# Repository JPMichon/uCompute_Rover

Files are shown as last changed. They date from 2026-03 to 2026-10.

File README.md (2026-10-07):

# 🤖 uCompute Rover

## [English version available here](./README.EN.md)



## 🛠️ Matériel requis
* 4 x Moteurs réductés CC — "TT Motor" — 200 RPM (3 à 6 VCC)
* 2 x DRV8833 — Contrôleurs de moteur double pont en H (1,5 A, 3 à 10 V)
* 1 x Module uCompute RP2040 ver 1.3 (Rover)
* 1 x uCompute-Rover ver 1.0
* 1 x Convertisseur abaisseur de tension DC-DC LM2596 (3 A ou équivalent)
* 1 x Boîtier pour 6 piles AA (ou équivalent)

## ⚙️ Options et extensions
* 1 x Micro-servomoteur SG90
* 1 x Capteur à ultrasons HC-SR04 / HCSR04
* 1 x Schéma de câblage du rover
* 1 x Interrupteur à bascule encastrable (*Snap-in*) 10x15 mm (ON-OFF)
* 2 x Modules radio nRF24L01+
* 1 x Module uCompute RP2040 ver 1.3 (Télécommande)
* 1 x Contrôleur à distance uCompute (*Remote controller*)
* 1 x Capteur de puissance et moniteur de tension/courant I2C INA219
* 1 x Module GPS GY-NEO-6M avec antenne active en céramique
* 1 x Capteur de distance laser ToF (*Time-of-Flight*) GY-530 VL53L0X
* 1 x Boussole magnétique à trois axes GY-271 QMC5883L (3V-5V)
* 1 x Caméra thermique infrarouge AMG8833 (Matrice de capteurs 8x8)
* 1 x Module haute précision de température, humidité et pression d'air I2C AHT20+BMP280
* 1 x Module d'analyse de la qualité de l'air (CO2, eCO2, TVOC) ENS160+AHT21
* *Tout autre module optionnel selon vos préférences.*

---

## ⚡Vue schématisé de l'électronique embarqué
<p align="center">

</p>

---

# 🔌 Architecture Électronique & Modularité

Le projet **uCompute Rover** repose sur une architecture matérielle entièrement modulaire. Ce dépôt se concentre spécifiquement sur le châssis, l'assemblage mécanique et la carte d'interface du rover (*Rover board*). 

Le « cerveau » et les différents modules de communication requis proviennent de l'écosystème global **RP2040 uCompute**.

---

## 🔗 Dépôt Parent & Documentation Électronique

Pour fabriquer, programmer ou comprendre le fonctionnement détaillé de la carte maîtresse et de ses modules, veuillez vous référer au dépôt principal :

👉 **[GitHub - RP2040 uCompute](https://github.com/JPMichon/RP2040_uCompute)**

Vous y trouverez :
* 📂 Les fichiers de conception matérielle (**Gerber**, schémas de circuits et listes de composants BOM).
* 📂 Les modules.
* 📍 La cartographie complète des ports et les spécifications techniques de la plateforme.

## Guide d'assemblages
Le guide est est séparé en 3 sections ( le matériel, l'électronique et le code ) soit :
* L'assemblage du Rover ce trouve dans le répertoire 📂 [**3D_Parts**](https://github.com/JPMichon/uCompute_Rover/blob/main/README.md)
* L'installation des capteurs et de l'électronique dans le répertoire 📂 [**Electronic**](https://github.com/JPMichon/uCompute_Rover/blob/main/Electronic/README.md)
* Validation du fonctionnement des composantes 📂 **testcode**
  
---

### 🧠 Le Cœur du Système : uCompute
L'intelligence embarquée du robot utilise la plateforme de développement autonome **uCompute** (basée sur le microcontrôleur Raspberry Pi RP2040). C'est elle qui gère l'exécution des scripts de pilotage (MicroPython), l'interface graphique de diagnostic et la centralisation des données des capteurs.<br>


---
### 💡 Une architecture ouverte et universelle

Bien que le projet soit conçu autour de l'écosystème **uCompute** (RP2040), le module de contrôle des moteurs a été développé dans un pur esprit de liberté logicielle et matérielle. L'ensemble de la structure est entièrement agnostique : le module de puissance utilise des signaux logiques **3.3v** . Cela signifie qu'un **maker** peut tout à fait adapter ce châssis et ce module d'extension pour les piloter avec un **ESP32**, un **Arduino** ou toute autre plateforme de développement de son choix, en bricolant son propre module de contrôle ou en utilisant les modules du projet et en adaptant simplement le câblage et le script de pilotage.<br>

 ### 🏎️💨 Pour les Makers plus exigeants
 Il est tout à fait envisageable d'intégrer une solution plus robuste, telle qu'un **Raspberry Pi**. L'utilisation d'un micro-ordinateur de ce calibre permet de gérer des tâches de calcul lourdes ou des scripts plus complexes. Il faudra cependant veiller à ajuster le module d'alimentation du circuit : contrairement aux microcontrôleurs classiques, un Raspberry Pi nécessite une source d'énergie stable et un **courant plus élevé (3A pour un PI 4 Model B) + (1A pour les 4 moteurs) = 4A 5V CC** pour assurer une stabilitée. Une fois cette adaptation électrique logicielle et matérielle effectuée, les possibilités de votre montage s'en trouveront démultipliées.<br>
 
**Libre à vous de créer un Frankenstein! 🧟‍♂️**

---

### 📻 Modules d'extension (Add-ons)
Pour assurer la liaison sans fil et la télémétrie bidirectionnelle avec la télécommande, le rover exploite les modules d'extension interchangeables du projet principal (notamment le module radio **NRF24L01+**).

👉 **[RP2040_uCompute Modules](https://github.com/JPMichon/RP2040_uCompute/tree/main/Modules)**

| Emplacement | Module | Description & Fonctionnalités | Rendu Visuel |
| :--- | :--- | :--- | :--- |
| **Socket Arrière** (Communication) | **Module Wi-Fi** (ESP-12F) | Carte d'adaptation avec ESP8266 pour une connectivité Wi-Fi. |   |
| **Socket Arrière** (Communication) | **Module Radio** (NRF24L01) | Carte d'adaptateur pour liaisons radio 2,4 GHz. |  |
| **Pins Header** <br> (Connecteur IOs) | **µCompute Remote** <br> (REV 1.0) | Module de commande analogue avec boutons. |  |
| **Pins Header** <br> (Connecteur IOs) | **µCompute Rover** <br> (REV 1.0) | Contrôleur de moteur DC (2+2) + Servo + HC-SR04 + Module GPS (Neo-6M). |  |

---

## 🎮 Contrôle à distance (Mode RC)

Le **uCompute Rover** intègre un mode de pilotage radiocommandé (RC) autonome. La télécommande est construite autour d'un second module uCompute équipé d'un joystick analogique, de boutons-poussoirs, d'un écran OLED **SSD1306** et d'un module radio **NRF24L01+**.

<p align="center">
  
</p>

### 📐 Conception mécanique et boîtier 3D
L'ergonomie de la manette a été spécialement étudiée pour offrir une prise en main confortable grâce à des poignées latérales intégrées. 

* 📁 Le fichier STL du boîtier est disponible ici : **[RC_remote_v1.stl](https://github.com/JPMichon/uCompute_Rover/blob/main/3D_Parts/RC_remote_v1.stl)**

### 💾 Scripts de test (MicroPython)
Le système s'appuie sur deux scripts distincts qui gèrent la communication bidirectionnelle en temps réel (envoi des commandes de pilotage et réception de la télémétrie sur l'écran OLED) :

1. **Côté Télécommande :** **[Remote_Rover_v1_SSD1306.py](https://github.com/JPMichon/uCompute_Rover/blob/main/testcode/Remote_Rover_v1_SSD1306.py)**
   * Initialise le bus SPI pour le module radio NRF24L01+.
   * Lit l'état du joystick analogique (axes X/Y) et des boutons de commande.
   * Gère l'affichage des informations système sur l'écran OLED local.
   * Transmet les paquets de commande vers le robot de manière périodique.

2. **Côté Rover :** **[RC_Rover_v1_SSD1306.py](https://github.com/JPMichon/uCompute_Rover/blob/main/testcode/RC_Rover_v1_SSD1306.py)**
   * Reste à l'écoute des paquets radio émis par la télécommande.
   * Décode les consignes de trajectoire et de vitesse pour piloter les moteurs CC via les ponts en H DRV8833.
   * Gère la sécurité (arrêt d'urgence automatique des moteurs en cas de perte de liaison radio).

---

## 🚀 Évolution vers un Rover Autonome et Télémétrie

Bien que le projet soit initialement présenté avec un mode de pilotage radiocommandé (RC), l'architecture matérielle du **uCompute Rover** a été pensée dès le départ pour la modularité. Grâce à ses nombreux capteurs embarqués, le robot peut très facilement être transformé en **véhicule 100 % autonome**.

### 🤖 Logique d'Autonomie Évolutive
La carte d'interface (*Roverboard*) interconnecte nativement tous les éléments essentiels pour permettre au microcontrôleur RP2040 de prendre des décisions en temps réel :
* **Évitement d'obstacles :** Le capteur à ultrasons **HC-SR04** (ou le capteur laser ToF **VL53L0X**) permet de cartographier l'environnement direct et d'adapter la trajectoire.
* **Navigation et orientation :** L'ajout de la boussole magnétique **GY-271** et du module GPS **NEO-6M** ouvre la voie à des algorithmes de navigation par points de passage (*waypoints*).

Le passage au mode autonome ne nécessite aucune modification matérielle majeure : il s'agit principalement d'un **déploiement logiciel** (scripts de contrôle de trajectoire automatique en MicroPython).

### 🌐 Pilotage par Interface Web (Wi-Fi)
Puisqu'un module **Wi-Fi (ESP-12F)** est disponible dans l'écosystème uCompute (conçu pour s'insérer sur le socket arrière de communication), les possibilités de contrôle à distance s'étendent au réseau IP. 

En déployant un micro-serveur HTTP en MicroPython sur l'uCompute, il devient possible de :
* **Piloter le rover depuis n'importe quel appareil** (smartphone, tablette ou PC) connecté au même réseau Wi-Fi, sans avoir besoin d'une manette physique.
* Créer une **interface web moderne et interactive** (boutons tactiles, sliders de vitesse, joystick virtuel en JavaScript) pour contrôler les mouvements du robot en toute simplicité.

  ### 📡 Liaison Longue Portée (LoRa)
Grâce au bus SPI exposé sur le socket arrière, l'intégration d'un module radio **LoRa** (comme le RFM95W ou équivalent) est également envisageable avec très peu d'efforts. Cette technologie permet d'étendre radicalement le rayon d'action du rover, autorisant la transmission de commandes et de télémétrie sur de très longues distances en extérieur (milieu rural ou urbain dense), là où le Wi-Fi ou les liaisons 2,4 GHz classiques s'essoufflent. 

*Note : Un add-on LoRa standardisé fait partie des pistes de réflexion et pourrait être officiellement disponible dans les prochaines évolutions de la plateforme uCompute.*

### 📊 Télémétrie Bidirectionnelle en Temps Réel
En mode autonome, les modules radio **NRF24L01+** changent de rôle. Au lieu de simplement recevoir des commandes de pilotage, le lien sans fil sert à renvoyer un flux constant de données (télémétrie) vers une station au sol (PC, console ou le module *uCompute Remote*) :
* Surveillance en temps réel de la tension et du courant consommé (via le capteur de puissance **INA219**).
* Transmission des coordonnées géographiques (GPS), du cap (boussole) et des conditions environnementales (température, pression via le **BME280**).
* Visualisation des données thermiques à distance si le capteur infrarouge **AMG8833** est installé.

*Un ensemble de scripts exemples dédiés à la navigation autonome et au protocole de communication de télémétrie sera progressivement ajouté au dossier `testcode`.*

---

# 🎯 Le projet idéal pour vous lancer

Vous rêvez de construire votre propre plateforme de robotique avancée, mais vous ne savez pas par où commencer ? Vous avez peur de manquer de temps, de connaissances en programmation ou d'expertise en électronique ? Vous craignez de vous perdre dans un fouillis de câbles qui se débranchent tout le temps, ou de bloquer vos élèves avec du code trop complexe ?

Le **uCompute Rover** a été créé précisément pour en finir avec ces frustrations.

## 🧠 Pas besoin d'être un expert pour débuter
* **Zéro programmation complexe :** Oubliez le C++ austère. Le robot est propulsé par le microcontrôleur RP2040 et se programme en **MicroPython**. C'est le langage le plus simple, le plus lisible et le plus rapide à apprendre aujourd'hui. En quelques lignes de code, votre robot avance.
* **Zéro blocage frustrant :** Grâce au système visuel intégré (*uComputeOS*), si vous ou l'un de vos élèves faites une erreur dans le code, l'écran affiche une alerte claire au lieu de faire planter complètement la carte. Vous comprenez l'erreur instantanément sans perdre de temps.

## 🛠️ Zéro soudure si vous le souhaitez !
* Vous pensez ne pas avoir le niveau pour souder de minuscules composants électroniques (CMS) ? Aucun problème. Bien que la carte finale soit ultra-propre, le projet est conçu pour être **100 % reproductible sur une simple plaque de prototypage (*Breadboard*)** avec un Raspberry Pi Pico ou Pico 2 classique à bas coût. C'est la solution idéale pour débuter rapidement à la maison ou équiper toute une classe avec un budget maîtrisé.

## 🚀 Une évolution sans limites, à votre rythme
Ne restez pas bloqué avec un robot jouet figé. Commencez par un châssis basique télécommandé en ligne droite, puis faites-le évoluer quand vous aurez le temps : ajoutez le Wi-Fi pour le piloter depuis votre smartphone, connectez un module radio longue portée, ou installez un GPS et un capteur de distance pour le rendre totalement autonome.

## 🛠️ Pour les Makers : Le bac à sable ultime
* **Modularité totale :** Finis les robots figés ou les amas de câbles *Dupont* instables. Grâce à son système de cartes filles interchangeables, faites évoluer votre rover au gré de vos envies : ajoutez le Wi-Fi (ESP-12F), la radio (NRF24L01+), le LoRa, un GPS ou de l'imagerie thermique sans jamais refaire le circuit principal.
* **Architecture ouverte :** Explorez des protocoles industriels et de communication standardisés (I2C, SPI, UART, PWM) sur une plateforme robuste et gratifiante.

## 🎓 Pour les Écoles & Projets Éducatifs : Une pédagogie sans friction
* **Barrière à l'entrée minimale :** Propulsé par le microcontrôleur RP2040 et les technologies d'uCompute, le rover permet aux étudiants de comprendre et d'obtenir des résultats concrets en seulement quelques lignes de code, bien plus rapidement qu'en C++.
* **Sécurité et tolérance aux erreurs :** Grâce à l'interface de diagnostic intégrée (*uComputeOS*), si le code d'un élève contient une erreur, la carte capture l'exception et affiche un écran d'alerte visuel au lieu de figer le robot. L'apprentissage se fait par expérimentation fluide, sans frustration.
* **Accessible à tous les budgets :** Si l'assemblage CMS d'origine demande de l'expertise, la plateforme est **100 % rétrocompatible sur plaque de prototypage (*Breadboard*)** avec un Raspberry Pi Pico ou Pico 2 standard. Vous pouvez équiper une classe entière à moindre coût !

*Le uCompute Rover vous fournit une base mécanique et électronique solide. Vous n'avez plus qu'à assembler les blocs, à votre rythme et selon vos compétences actuelles.*

---

## 📜 Licence

Le matériel (fichiers de conception, schémas, typons) et les logiciels de ce projet sont mis à disposition selon les termes de la Licence **Creative Commons Attribution - Pas d'Utilisation Commerciale - Partage dans les Mêmes Conditions 4.0 International (CC BY-NC-SA 4.0)**.

❌ **L'utilisation commerciale de ce projet (revente de PCBs nus, kits ou cartes retroPico assemblées) est strictement interdite sans autorisation préalable de l'auteur.**

Consultez le fichier [LICENSE](LICENSE) pour lire l'intégralité des termes.

---

## ☕ Soutenir le projet

Si vous appréciez mon travail et souhaitez m'offrir un café pour me soutenir bénévolement dans mes futurs projets de soudure et de code, vous pouvez me laisser un [**pourboire sur Ko-fi** ](https://ko-fi.com/jpmichon) . C'est entièrement volontaire et grandement apprécié !

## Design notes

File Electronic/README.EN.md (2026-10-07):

# ⚡ uCompute Rover Wiring

This directory contains all the necessary information to assemble, wire, and power the robot's electronic components.

## 🗺️ Schematic View of the Onboard Electronics
<p align="center">

</p>

---

# Assembly Guide

<br>

## ⚙️ Motor Installation

### **You will need:** <br>
• 8 screws (25 mm x 3 mm), <br>
• 4 self-tapping screws (3 mm x 5 mm), <br>
• 4 all-terrain wheels, <br> 
• 4 TT dual-shaft DC motors 3-6 V, 200 RPM ratio, 1:48 reduction, <br>      
 <br>

**Extend the motor wires as needed**: My prototype version uses **JST-XH 2.54 2-pin** connectors.<br> 
Feel free to use your own setup.

Each motor is connected using a 26 AWG two-conductor wire measuring approximately **30 cm**.

### Steps:

| Insert the wire into the top hole | Insert each wire on each side | Solder the wires to the motor terminals | Secure the motor using screws | Route the other end out the bottom of the electronics plate | Add a sticker on the axles of the 4 motors |
| :---: | :---: | :---: | :---: | :---: | :---: |
|  |  |  |  |  |  

>[!NOTE]
> To **save yourself some time**, make sure to always solder the positive and negative terminals in the same order, as the power module reverses the polarity of the second motor on the same **side**. **This means that if the motors run backward** instead of forward, **you must** swap the connectors between the two motors. <br>
> <br>
> Another element: the **right and left motors operate in pairs**. **That is to say**, the **two** motors on the same side are wired to be synchronous. This reduces **the number of I/Os (IOs)** required to control the motors. The other advantage is that it makes it easier to use **tracks** without having to implement software safeguards, while allowing for more features on the Rover Board. However, **every advantage has its drawbacks**, and this configuration **does not allow** for the use of **Mecanum wheels**. Since the **uCompute Rover is modular** and the schematics are available, **it is relatively simple to DIY your own** motor control module. It is not impossible that in the near future, I might add a specific module to control **Mecanum wheels**.

## ⚙️ Installing the Control Modules

### **You will need:** <br>
• 1 x RP2040 uCompute module,<br>
• 1 x uCompute Rover module,<br>
• 2 x DRV8833 modules,<br>
• 8 self-tapping screws (3 mm x 5 mm),<br>

### Installation:

| Prepare 4 mounting screws | Secure the <br> RP2040 uCompute module | Prepare 4 mounting screws | Secure the <br> uCompute Rover module | Connect the right <br> and left motors | Insert the DRV8833 modules <BR> (Output pins facing down) |
| :---: | :---: | :---: | :---: | :---: | :---: |
| |  |  |  |  | 

## ⚙️ Installing the Power Switch
### **You will need:** <br>
• 1 x 24 AWG two-conductor wire, approximately 20 cm,<br>
• 1 x SPST rocker switch, model: **KCD11 (10X15mm)**,<br>

### Installation:

| Solder the wires to the switch terminals | Insert the switch into the square hole on the control panel |
| :---: | :---: |
||

## :scissors: Mounting the Power Supply
This section is simple, yet effective…<BR>
The easiest way to hold the various components in place is by using Velcro strips.<br>
_If it's good enough for NASA, it's good enough for the Rover!_

### Steps:

| Stick a Velcro strip <br> on the top shelf | Stick Velcro strips <br> under the battery holder | Stick a Velcro strip <br> under the regulator | Test the installation |
| :---: | :---: | :---: | :---: |
| | |||

## ⚙️ Preparing and Installing the NeoPixel Strip

> [!NOTE]
> Only available for the `frontal_sensor_v3.stl` which natively integrates the **NeoPixel** strip.

### **You will need:** <br>
• 3 x wires with a female **DuPont** connector on one end, approximately **25 cm** long,<br>
• 1 x **NeoPixel** strip with 8 addressable **WS2812B** (5050) LEDs,<br>
• 2 self-tapping screws (3 mm x 5 mm),<br>

### Steps:

| View of the NeoPixel strip | Solder the wires <br> to the side labeled DI | Result | Prepare 2 mounting screws | Secure the NeoPixel module <br> underneath the sonar |
| :---: | :---: | :---: | :---: | :---: |
| |  |  |  | |

## :scissors: Installing the HC-SR04 Sonar
For this part, you will need **hot glue…** <br>
Hooray for crafting! <br>

### **You will need:** <br>
• 4 x wires with female-to-female **DuPont** connectors, approximately **25 cm** long,<br>
• 1 x HC-SR04 Sonar Module<br>

### Steps:

| Installing the **DuPont connectors** <br> on the sonar | Installing the sensor in its housing <br> use a little hot glue to secure it |
| :---: | :---: |
|||

> [!NOTE]
> Hot glue has a melting point around 190°C (374°F), which is very close to 3D printing temperatures. <br>
> **Use hot glue sparingly** to avoid warping your printed parts.

## ⚙️ Installing the Servo Motor
### **You will need:** <br>
• 1 x **SG90 Mini Gear Micro 9g** Servo or equivalent,<br>
• 2 self-tapping screws (2 mm x 5 mm) (usually included with the Servo).<br>

### Steps:

| Servo Image | Prepare 2 Screws | Secure the Servo <br> to the Mount |
| :---: | :---: | :---: |
| |  | |

## ⚙️ Preparing the LM2596
### **You will need:** <br>
• 1 x 24 AWG two-conductor wire, approximately 10 cm,<br>
• 1 x 24 AWG two-conductor wire, approximately 15 cm, with a **JST XH2.54 2P** connector on one end,<br>
• 1 x **LM2596 DC-DC buck converter** module,<br>

### Steps:

| Solder the wires<br> + Red, - Black | Close-up of the <br> JST XH2.54 2P connector | 
| :---: | :---: |
|||

> [!WARNING]
> ### ⚡ WARNING: Mandatory Tuning of the LM2596 Regulator
> The Rover module strictly requires a **5V** power supply voltage. Since the LM2596 DC-DC converter is an **adjustable** regulator, it is **crucial to adjust its output voltage to 5V using a multimeter BEFORE connecting it** to the Rover's electronic boards.
> 
> Connecting the regulator without prior adjustment or with a voltage that is too high will lead to the **immediate destruction** of the RP2040 microcontroller, the LCD screen, and all of your sensors.

### Adjusting the Regulator

**Using a multimeter and a small flathead screwdriver, adjust the voltage by turning the potentiometer screw (indicated in the photo below).**
> 🔄 **Potentiometer Adjustment Direction:**
> * **To DECREASE the voltage:** Turn the screw **counterclockwise**.
> * **To INCREASE the voltage:** Turn the screw **clockwise**.
> 
> *Note: These multi-turn potentiometers often have a wide initial adjustment range. It is completely normal to have to complete several full turns (sometimes more than 10 to 15 turns) before seeing the voltage begin to change on your multimeter. Proceed gently with small adjustments once you are close to 5V.*

<p align="center">

</p>

## 🔋 Power Supply Diagram

The Rover is powered by a 6-AA battery pack (or equivalent). The voltage is stepped down to **5V (2A min)** via the LM2596 module to power the main board, the motors, and the servo motor.

<p align="center">

</p>

---

## Final Connections
The power supply, the HC-SR04 Sonar, and the Servo all connect to this specific location on the control board.<br>
The **NeoPixels** connect directly to the uCompute board.<br>

The motors were already connected in the previous steps. If they aren't, you can connect them now.<br> 

### Steps:

| Close-up of the connectors | Once connected | Connect the NeoPixel <br> directly to the uCompute | Connect the INA219 <br> to the back of the uCompute |
| :---: | :---: | :---: | :---: |
| |  | ||

## Cable Management (Optional):

### **You will need:** <br>
• A **sufficient quantity** of **10 cm cable ties (zip ties / tie-wraps)**.<br>
• A pair of **wire cutters** to trim off the excess.

Although optional, this part is nevertheless important if you **want** a reliable project over time. The horizontal pieces were designed with notches to make cable management easier, allowing the use of **10 cm cable ties (zip ties)** to secure the **cables** firmly. Feel free to use them as you see fit.

### Location of the notches<br>


## GPS Connection
**Coming soon**

## Telecommunication Module Connection
**Coming soon**

---

# EXTRA

## More than one I2C sensor? No problem!
There is a good chance you will want to include more than one I2C sensor in your project. The solution is quite simple and can be achieved by connecting them in parallel using a quick DIY trick.

### DIY Details

| Top View | Soldering Details | 
| :---: | :---: |
| |  |

> [!NOTE]
> 💡 **Important note regarding the I2C bus**
> * The I2C bus requires two pull-up resistors—one on SDA and one on SCL—connected to VCC to function properly.
> * Most ready-to-use sensor modules (breakout boards) already include these built-in resistors.
> * Connecting too many modules in parallel drops the total pull-up resistance (Ohm's law / resistors in parallel). If you connect more than 3 or 4 sensors, the signal quality may degrade.
> 
> ⚠️ **In case of issues:** If you experience communication errors, you will need to remove (unsolder) the pull-up resistors from some of the modules to keep only a single pair on the entire bus.

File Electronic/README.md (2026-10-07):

# ⚡ Câblage du uCompute Rover

Ce répertoire regroupe toutes les informations nécessaires pour assembler, câbler et alimenter les composants électroniques du robot.

## 🗺️ Vue schématisée de l'électronique embarquée
<p align="center">


</p>

---

#  Guide de montage

<br>

## ⚙️ Installation des moteurs

### **Vous aurez besoin de:** <br>
• 8 vis de (25 mm x 3 mm), <br>
• 4 vis perçante de (3 mm  x 5 mm), <br>
• 4 roues tout-terrain, <br> 
• 4 moteurs TT double CC 3-6 V Rapport 200 tr/min, réduction 1:48, <br>      
 <br>

**Alonger les fils des moteurs aux besoins** :  Ma version prototype utilise des connecteurs **JST-XH 2.54 2-pin**<br> 
Libre à vous d'utiliser votre propre recette.

Chaque moteur est raccordé par un fil à deux conducteurs de calibre 26 AWG d'environ **30 cm**.

### Étapes:
| Insérer le fil dans le trou du haut | Insérer chaque fil de chaque côté | Souder les fils aux bornes du moteur | Sécuriser le moteur à l'aide de vis | Sortir l'autre extrémité dans le bas de la plaque électronique | Ajouter un collant sur les axes des 4 moteurs 
| :---: | :---: | :---: | :---: | :---: | :---: |
|  |  |  |  |  |  

>[!NOTE]
> Afin de **vous faire gagner du temps**, assurez-vous de toujours souder la borne positive et la borne négative dans le même ordre, car le module de puissance inverse la polarité du second moteur d’un même **côté**. **Cela signifie que si les moteurs reculent** au lieu d’avancer, **il faut** inverser les connecteurs entre les deux moteurs. <br>
> <br>
> Autre élément : les **moteurs droit et gauche fonctionnent** par **paire**. **C'est-à-dire** que les **deux** moteurs d’un même côté sont câblés pour être synchrones. Cela permet de diminuer **le nombre d'E/S (IOs)** requis pour piloter les moteurs. L’autre avantage est de faciliter l’utilisation de **chenilles** sans devoir mettre en place des garde-fous logiciels, tout en permettant plus de fonctionnalités sur le Rover Board. Cependant, **tout avantage ayant ses inconvénients**, cette configuration **ne permet pas** l’utilisation de **roues Mecanum**. Comme le **uCompute Rover est modulaire** et les schémas sont disponibles, **il est relativement simple de bricoler votre propre module** de contrôle des moteurs. Il est impossible, que dans un avenir plus ou moins rapproché, j'ajoute un module spécifique pour piloter des **roues Mecanum**.

## ⚙️ Installation des modules de controle

### **Vous aurez besoin de:** <br>
• 1 x module RP2040 uCompute,<br>
• 1 x uCompute Rover module,<br>
• 2 x Module DRV8833
• 8 vis perçante de (3 mm  x 5 mm), <br>

### Installation:
| Préparer 4 vis de montage | Fixer le module <br> RP2040 uCompute | Préparer 4 vis de montage | Fixer le module <br> uCompute Rover | Raccorder les moteurs <br> droite et gauche | Insérer les modules DRV8833 <BR> (broches Output vers le bas)|
| :---: | :---: | :---: | :---: | :---: | :---: |
| |  |  |  |  | 

## ⚙️ Installation de l'interrupteur d'alimentation
### **Vous aurez besoin de:** <br>
• 1 x fil à deux conducteurs de calibre **24 AWG** d'environ **20 cm**.,<br>
• 1 x un interrupteur à bascule SPST modele: **KCD11 (10X15mm)**,<br>

### Installation:
| Souder le fils sur les bornes de l'interrupteur | Insérer l'interrupteur dans le trou carré du panneau de controle |
| :---: | :---: |
||

## :scissors: Fixation de l'alimentation
Cette section est simple, mais efficace…<BR>
Pour maintenir en place les différents composants, la façon la plus simple reste l’utilisation de bandes Velcro.<br>
_Si c’est assez bon pour la NASA, c’est bon pour le Rover !_

### Étapes:
| Coller une bande de Velco <br> sur la tablette du haut | Coller des bandes de Velco <br> sous le porte-piles | Coller une bande de Velco <br> sous le régulateur | Tester l'installation |
| :---: | :---: | :---: | :---: |
| | |||

## ⚙️ Préparation et installation de la bande NeoPixel

> [!NOTE]
> Seulement disponible pour le  `frontal_sensor_v3.stl` intégrant nativement la bande **Neopixel**.
> 
### **Vous aurez besoin de:** <br>
• 3 x fils avec connecteur **DuPont** femelle a l'un des bouts. Longueur environ **25 cm**,<br>
• 1 x bande **Neopixel** de 8 x **WS2812B** (5050) adressables,<br>
• 2 vis perçante de (3 mm  x 5 mm), <br>

### Étapes:
| Vue de la bande Neopixel | Souder les fils <br> sur le coté  avec DI  | Résultat | Préparer 2 vis de montage | Fixer le module NeoPixel <br> sous le sonar |
| :---: | :---: | :---: | :---: | :---: |
| |  |  |  | |

## :scissors: Installation du Sonar HC-SR04
Pour cette partie, vous aurez besoins de **colle chaude…** <br>
Vivement l'artisanat! <br>

### **Vous aurez besoin de:** <br>
• 4 x fils avec connecteur **DuPont** femelle au deux bouts. Longueur environ **25 cm**,<br>
• 1 x Module de Sonar HC-SR04<br>

### Étapes:
| Installation des **fiches Dupont** <br> sur le sonar | Installation du capteur dans son socle <br> un peu de colle chaude pour le tenir en place |
| :---: | :---: |
|||

> [!NOTE]
> La colle chaude a un point de fusion au alentour de 190 °C. très près des températures d'impression des pièces en 3D. <br>
> **Allez y parcimonieusement** avec la colle chaude pour évitez de déformer vos pièces.

## ⚙️ Installation du servo moteur
### **Vous aurez besoin de:** <br>
• 1 x **SG90 Mini Gear Micro 9g** Servo ou équivallent,<br>
• 2 vis perçante de (2 mm  x 5 mm). (généralement inclus avec le Servo). <br>
### Étapes:
| Image du servo | Préparer 2 vis | Fixer le servo <br> au support |
| :---: | :---: | :---: |
| |  | |

## ⚙️ Préparation du LM2596
### **Vous aurez besoin de:** <br>
• 1 x fil à deux conducteurs de calibre **24 AWG** d'environ **10 cm**.,<br>
• 1 x fil à deux conducteurs de calibre **24 AWG** d'environ **15 cm**  avec un connecteur **JST XH2.54 2P** à l'un des bout,<br>
• 1 x un module **convertisseur DC-DC LM2596**,<br>
### Étapes:
| Souder les fils<br>  + rouge, - Noir | Gros plan sur le  <br>connecteur JST XH2.54 2P | 
| :---: | :---: |
|||

> [!WARNING]
> ### ⚡ ATTENTION : Réglage impératif du régulateur LM2596
> Le module du Rover requiert une tension d'alimentation stricte de **5 V**. Le convertisseur DC-DC LM2596 étant un régulateur **ajustable**, il est **crucial d'ajuster sa tension de sortie à 5 V à l'aide d'un multimètre AVANT de le connecter** aux cartes électroniques du Rover. 
> 
> Brancher le régulateur sans réglage préalable ou avec une tension trop élevée entraînera la **destruction immédiate** du microcontrôleur RP2040, de l'écran LCD et de l'ensemble de vos capteurs.

### Ajustement du régulateur

**À l’aide d’un multimètre et d’un petit tournevis plat, ajustez la tension en tournant la vis du potentiomètre (indiquée sur la photo ci-dessous).**
> 🔄 **Sens de réglage du potentiomètre :**
> * **Pour DIMINUER la tension :** Tournez la vis dans le **sens inverse des aiguilles d'une montre** (antihoraire).
> * **Pour AUGMENTER la tension :** Tournez la vis dans le **sens des aiguilles d'une montre** (horaire).
> 
> *Note : Ces potentiomètres multitours possèdent souvent une large plage de réglage initiale. Il est tout à fait normal de devoir effectuer plusieurs tours complets (parfois plus de 10 à 15 tours) avant de voir la tension commencer à varier sur votre multimètre. Procédez par petits gestes une fois proche des 5 V.*

<p align="center">

</p>

## 🔋 Schéma de l'alimentation électrique

Le Rover est propulsé par un boîtier de 6 piles AA (ou équivalent). La tension est abaissée à **5 V (2 A min)** via le module LM2596 pour alimenter la carte principale, les moteurs et le servomoteur.

<p align="center">

</p>

---

## Le branchement finale
L'alimentation, le Sonar HC-SR04 et le Servo ce connecte tous a cet endroit sur la carte de controle.<br>
Les **Neopixels** ce connecte directement sur le uCompute.<br>

Les moteurs ont déjà été connecté précédemment. Si il ne le sont pas, vous pouvez les connecter. <br> 

### Étapes:
| Gros plan sur les connecteurs | une fois connectés| Branchez le Neopixel <br> directement sur le uCompute | Branchez le INA219 <br> à l'arrière du uCompute |
| :---: | :---: | :---: | :---: |
| |  | ||

## Gestion du câblage (facultatif):

### **Vous aurez besoin de:** <br>
• **Serre-câbles (Tie-Wraps)** de **10 cm** en nombre **suffisant**.<br>
• Une paire de **pinces coupantes** pour retirer la partie superflue.

Bien que facultative, cette partie est néanmoins importante si vous **désirez** avoir un projet fiable dans le temps. Les pièces horizontales ont été conçues avec des encoches pour faciliter la gestion du câblage en permettant l'utilisation de **serre-câbles (Tie-Wraps) de 10 cm** afin de retenir solidement les **câbles**. Libre à vous de les utiliser à bon escient.

### Localisation des encoches<br>


## Le branchement du GPS
**a venir**

## Le branchement du module de télécommunication
**a venir**

---

# EXTRA

## Plus d'un capteur I2C ? Pas de problème !
Il y a de fortes chances pour que vous désiriez avoir plus d'un capteur I2C dans votre projet. La solution est assez simple et se résout par un branchement en parallèle à l'aide d'un petit bricolage maison.

### Détail du bricollage
| Vu du dessus | Détail des soudures | 
| :---: | :---: |
| |  |

> [!NOTE]
> 💡 **Note importante sur le bus I2C**
> * Le bus I2C a besoin de deux résistances de tirage (*pull-up*), une sur SDA et une sur SCL, reliées au VCC pour fonctionner correctement.
> * La plupart des modules de capteurs prêts à l'emploi (shields/breakouts) intègrent déjà ces résistances.
> * Connecter trop de modules en parallèle fait chuter la résistance totale de tirage (loi d'Ohm / résistances en parallèle). Si vous connectez plus de 3 ou 4 capteurs, le signal peut se dégrader.
> 
> ⚠️ **En cas de problème :** Si vous rencontrez des erreurs de communication, il faudra retirer (dessouder) les résistances de tirage de certains modules pour n'en garder qu'une seule paire sur tout le bus.

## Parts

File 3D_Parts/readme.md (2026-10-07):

# Impression du Rover

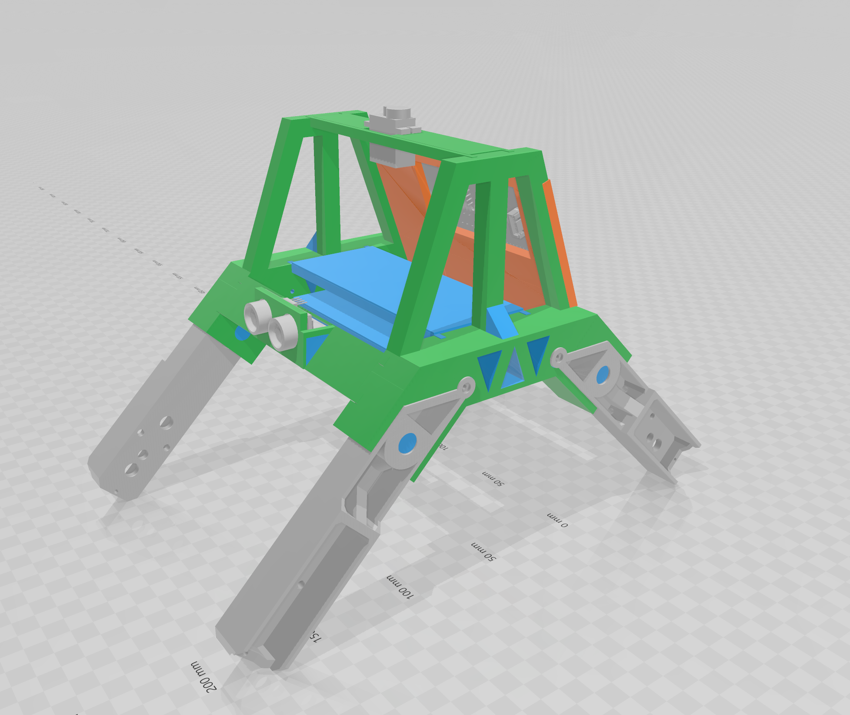
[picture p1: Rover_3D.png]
3D View


## Voici un tableau récapitulatif des pièces à imprimer.

| Catégorie | Nom de la pièce | Fichier STL recommandé | Quantité | Taux de remplissage (Infill) suggéré | Notes et spécificités |
| :--- | :--- | :--- | :---: | :---: | :--- |
| **Structure Principale** | **Les Côtés** | `Rover_Side_L_fixed.stl`<br>`Rover_Side_R_fixed.stl` | **2** <br>*(1 gauche / 1 droit)* | **30 %** | Côtés latéraux du Rover. |
| **Structure Principale** | **Les Jambes** | `Rover_Legs_V4.stl` | **2** | **30 %** | La version **V4** permet d'utiliser des vis de **25 mm x 3 mm**. Pièce mécanique sollicitée. |
| **Structure Principale** | **Détection de Collision** | `frontal_sensor_v3.stl` | **1** | **30 %** | La version **v3** permet d'accueillir un module de **8 Neopixels** en plus du capteur **HC-SR04**. |
| **Structure Principale** | **Tablette** | `Tablette.stl` | **2** | **30 %** | Support structurel de base et logement pour les batteries. |
| **Structure Principale** | **Tablette du Haut** | `Servo_plate_v2.stl` | **1** | **30 %** | Reçoit un **servo-moteur 9g** et sert de support pour les antennes. |
| **Électronique & Capteurs**| **Tableau Électronique** | `Electronic_plate_v2_uCRP2040.stl` | **1** | **30 %** | Conçu pour la carte **RP2040 Ucompute V1.3**. |

Il n'y a pas de recommandation spécifique sur le type de plastique, mon POC a été imprimé en PLA. Profitez-en pour utiliser vos restants de rouleau, **soyez créatifs !**

## Vue des pièces imprimés



A noter sur la photo, les **jambes** (En rouge) sont déjà assemblées aux pièces latérales (**côtés**) en blanc. Elles sont simplement insérées en presse-fit. 

> [!NOTE]
> Sur l'image, la version 2 du support du **HC-SR04** `frontal_sensor_v2.stl` été imprimé.<br> Je vous suggère d'imprimer la version 3 du support `frontal_sensor_v3.stl`.

---

# 🛠️ Guide d'Assemblage – uCompute Rover
Ce guide détaille les étapes nécessaires pour assembler la structure mécanique et les supports électroniques du Rover.

## 📋 Étape 1 : Inventaire et Impression des Pièces
Avant de commencer, assurez-vous d'avoir imprimé l'ensemble des composants nécessaires en quantité suffisante :

### Pièces structurales et de liaison<br>
• **Les côtés (2x)** : 1x `Rover_Side_L_fixed.stl` (Gauche) et 1x `Rover_Side_R_fixed.stl` (Droit).<br>
• **Les Jambes (2x)** : Imprimer deux fois le fichier <br>
• **Tablette (2x)** : Imprimer deux fois le fichier `Tablette.stl`. Servent de support structurel et de bac pour les batteries.

### Pièces structurales transversales<br>
• **Tablette du haut (1x)** : `Servo_plate_v2.stl` (Support pour servo 9g et antennes).<br>
• **Détection de collision (1x)** : `frontal_sensor_v3.stl`.<br>
• **Le tableau électronique (1x)** : `Electronic_plate_v2_uCRP2040.stl` (Pour la carte RP2040 Ucompute V1.3).

>[!NOTE]
> Une version pour la carte RP2350 Ucompute2 V1.1 est en conception <br>

## 🔧 Étape 2 : Pré-assemblage des Train de Roulement (Jambes et Côtés)<br>
1. **Insertion à blanc** : Insérez les Jambes (en rouge sur les photos de référence) dans les Pièces latérales (côtés droit et gauche).<br>
2. **Fixation** : Les pièces sont conçues pour s'ajuster en "presse-fit" (serrage mécanique).<br>

## 📐 Étape 3 : Assemblage du Châssis Central (Les Tablettes)

1. **Positionnement des tablettes basses :** Prenez les deux pièces *Tablette* imprimées. Elles viennent relier les blocs latéraux gauche et droit afin de fermer le châssis en largeur.
2. **Sécurisation :** Fixez-les solidement ; ces tablettes vont rigidifier l'ensemble du Rover et serviront plus tard de logement pour vos batteries et composants lourds.
3. **Ajout de la Tablette du haut :** Installez la plaque `Servo_plate_v2`. Intégrez-y le servomoteur 9g et fixez le support pour les antennes avant de refermer complètement la partie supérieure.

| Tablettes | Tablettes | Tablette haut | Tablette haut |  Vue haut | Support avant | Plaque electronique |
| :---: | :---: | :---: | :---: | :---: | :---: | :---: |
|  |  |  | |   |  | 
<br>

### Le uCompute Rover assemblé :
<br>
<p align="center">

</p>

## 📡 Étape 4 : Intégration des Capteurs et de l'Électronique<br>
1. **Module de détection frontal** : Assemblez le module de détection de collision à l'avant du robot.<br>
2. **Plaque électronique** : Installez le tableau électronique (Electronic_plate) conçu pour votre carte RP2040 Ucompute V1.3.<br>
3. **Fixation**:Fixez la carte sur son support avant de connecter les câbles des moteurs, du servo et des capteurs frontaux. Utiliser 4 vis perçantes (_ou faire des petits trous_) de (8 mm x 3mm) 2 par côté.<br>
4. **Sécurisation du Ucompute et du Rover module** : Utiliser des vis de (8 mm x 3mm).

## 🧐 Étape 5 : Vérification Finale<br>
• **Vérification de l'équerrage** : Posez le Rover sur une surface plane pour vérifier l'alignement des jambes et de l'empattement (comme illustré sur la vue 3D de l'assemblage final).<br>

## 🔒 Étape 6 : Sécurisation de la structure (_Optionnelle mais recommandée_) <br>
•  Pour garantir une robustesse structurelle et éviter que les vibrations ne séparent les pièces, appliquez une goutte de colle cyanoacrylate (_Crazy Glue_) au niveau des mortaises de liaison entre les pièces.

## La suite du montage est dans la section électronique!
**[ Pour vous y rendre ](https://github.com/JPMichon/uCompute_Rover/blob/main/Electronic/README.md)**

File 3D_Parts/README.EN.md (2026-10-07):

# Printing the Rover

3D View

## Here is a summary table of the parts to be printed.

| Category | Part Name | Recommended STL File | Quantity | Suggested Infill | Notes and Specifics |
| :--- | :--- | :--- | :---: | :---: | :--- |
| **Main Structure** | **Sides** | `Rover_Side_L_fixed.stl`<br>`Rover_Side_R_fixed.stl` | **2** <br>*(1 left / 1 right)* | **30%** | Lateral sides of the Rover. |
| **Main Structure** | **Legs** | `Rover_Legs_V4.stl` | **2** | **30%** | The **V4** version allows the use of **25 mm x 3 mm** screws. High-stress mechanical part. |
| **Main Structure** | **Collision Detection** | `frontal_sensor_v3.stl` | **1** | **30%** | The **v3** version accommodates an **8-Neopixel** module in addition to the **HC-SR04** sensor. |
| **Main Structure** | **Shelf** | `Tablette.stl` | **2** | **30%** | Base structural support and battery housing. |
| **Main Structure** | **Top Shelf** | `Servo_plate_v2.stl` | **1** | **30%** | Holds a **9g servo motor** and serves as a support for the antennas. |
| **Electronics & Sensors**| **Electronics Board** | `Electronic_plate_v2_uCRP2040.stl` | **1** | **30%** | Designed for the **RP2040 Ucompute V1.3** board. |

There is no specific recommendation regarding the type of plastic; my POC (Proof of Concept) was printed in PLA. Feel free to use your leftover filament spools, **be creative!**

## View of the Printed Parts



Note in the photo, the **legs** (in red) are already assembled to the white lateral pieces (**sides**). They are simply press-fitted together. 

> [!NOTE]
> In the image, version 2 of the **HC-SR04** mount (`frontal_sensor_v2.stl`) was printed.<br> I suggest you print version 3 of the mount (`frontal_sensor_v3.stl`).

---

# 🛠️ Assembly Guide – uCompute Rover
This guide details the steps required to assemble the mechanical structure and electronics supports of the Rover.

## 📋 Step 1: Inventory and Parts Printing
Before starting, ensure you have printed all the necessary components in sufficient quantities:

### Structural and Connecting Parts<br>
• **Sides (2x)**: 1x `Rover_Side_L_fixed.stl` (Left) and 1x `Rover_Side_R_fixed.stl` (Right).<br>
• **Legs (2x)**: Print the file twice.<br>
• **Shelf (2x)**: Print the `Tablette.stl` file twice. These serve as structural supports and battery bays.

### Transverse Structural Parts<br>
• **Top Shelf (1x)**: `Servo_plate_v2.stl` (Support for 9g servo and antennas).<br>
• **Collision Detection (1x)**: `frontal_sensor_v3.stl`.<br>
• **Electronics Board (1x)**: `Electronic_plate_v2_uCRP2040.stl` (For the RP2040 Ucompute V1.3 board).

>[!NOTE]
> A version for the RP2350 Ucompute2 V1.1 board is currently under design.<br>

## 🔧 Step 2: Pre-assembling the Drivetrain (Legs and Sides)<br>
1. **Dry fit**: Insert the Legs (in red in the reference photos) into the Lateral Pieces (right and left sides).<br>
2. **Securing**: The parts are designed for a mechanical "press-fit" alignment.<br>

## 📐 Step 3: Central Chassis Assembly (The Shelves)

1. **Positioning the low shelves:** Take the two printed *Shelf* parts. They connect the left and right side blocks to enclose the chassis widthwise.
2. **Securing:** Fasten them securely; these shelves will stiffen the entire Rover assembly and will later serve as the housing for your batteries and heavy components.
3. **Adding the Top Shelf:** Install the `Servo_plate_v2` plate. Integrate the 9g servo motor and secure the antenna support before fully closing the upper section.

| Shelves | Shelves | Top Shelf | Top Shelf | Top View | Front Support | Electronics Plate |
| :---: | :---: | :---: | :---: | :---: | :---: | :---: |
|  |  |  | |   |  | 
<br>

### The assembled uCompute Rover:
<br>
<p align="center">

</p>

## 📡 Step 4: Sensor and Electronics Integration<br>
1. **Front detection module**: Assemble the collision detection module to the front of the robot.<br>
2. **Electronics board**: Install the electronics plate designed for your RP2040 Ucompute V1.3 board.<br>
3. **Fastening**: Secure the board to its support before connecting the cables for the motors, servo, and front sensors. Use 4 self-tapping screws (*or drill small pilot holes*) of (8 mm x 3 mm), 2 on each side.<br>
4. **Securing the Ucompute and Rover module**: Use (8 mm x 3 mm) screws.

## 🧐 Step 5: Final Inspection<br>
• **Alignment check**: Place the Rover on a flat surface to verify the alignment of the legs and the wheelbase (as shown in the 3D view of the final assembly).<br>

## 🔒 Step 6: Securing the Structure (*Optional but recommended*)<br>
• To ensure structural robustness and prevent vibrations from separating the parts, apply a drop of cyanoacrylate glue (*Crazy Glue*) to the interlocking joints between the pieces.

## The next assembly steps are in the electronics section!
**[ Go to Electronics Section ](https://github.com/JPMichon/uCompute_Rover/blob/main/Electronic/README.EN.md)**

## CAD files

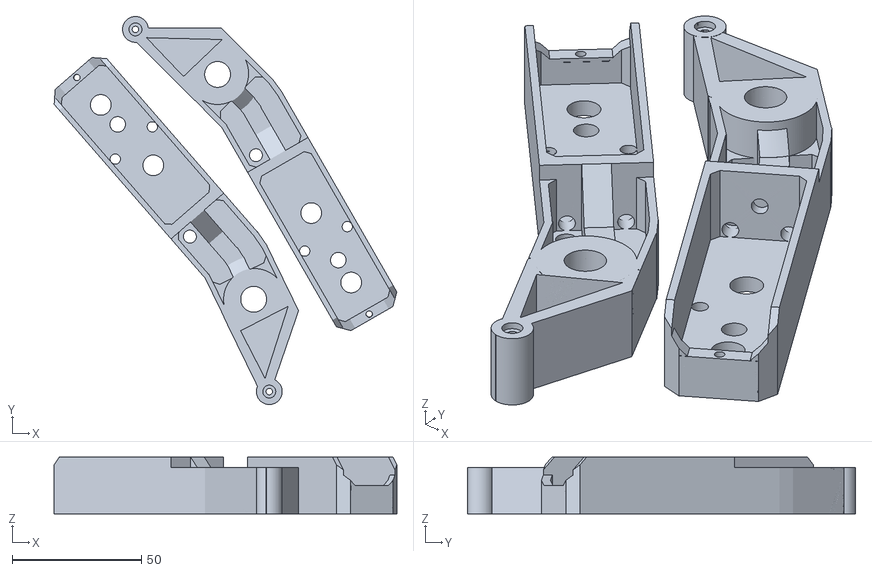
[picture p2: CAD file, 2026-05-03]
3D_Parts/Rover_Legs_shortwheelbase_V5.stl
132.7 x 150.2 x 22.0

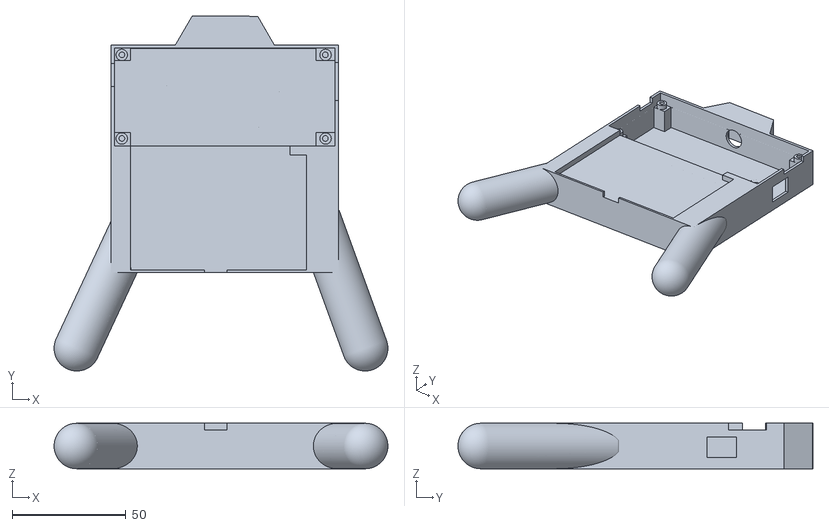
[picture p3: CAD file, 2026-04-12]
3D_Parts/RC_remote_v1.stl
146.6 x 155.9 x 20.0

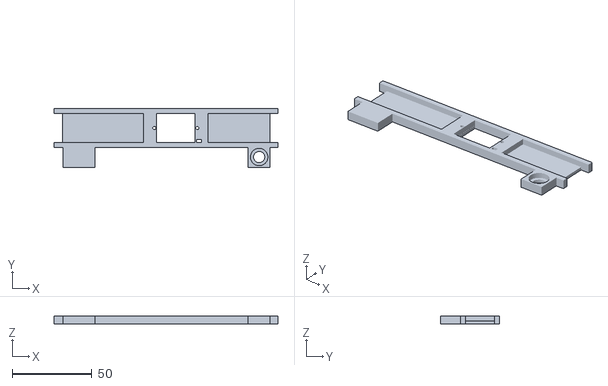
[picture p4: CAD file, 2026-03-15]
3D_Parts/Servo_plate_v2.stl
140.1 x 36.8 x 5.00

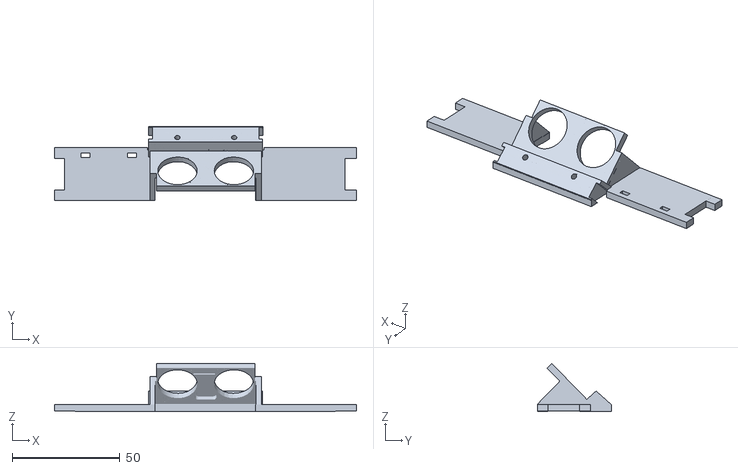
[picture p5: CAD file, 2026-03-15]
3D_Parts/frontal_sensor_v3.stl
140.0 x 34.5 x 22.3

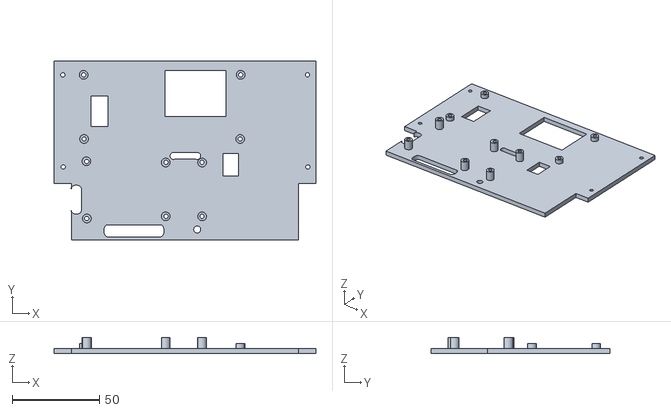
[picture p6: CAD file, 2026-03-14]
3D_Parts/Electronic_plate_v2_uCRP2040.stl
150.0 x 102.3 x 9.29

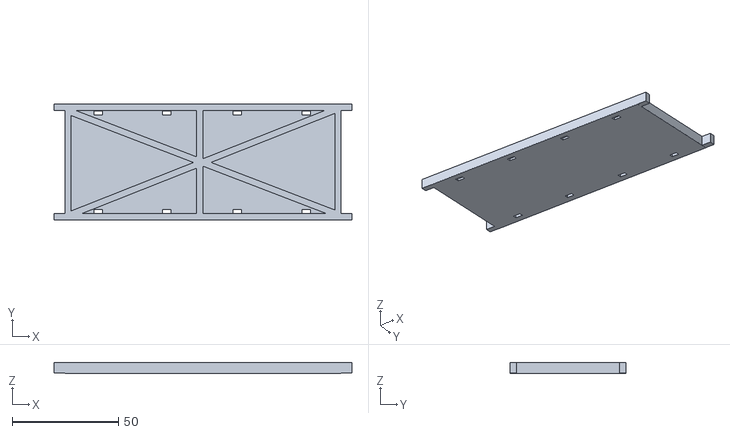
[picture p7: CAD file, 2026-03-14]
3D_Parts/Tablette.stl
140.0 x 54.5 x 5.08

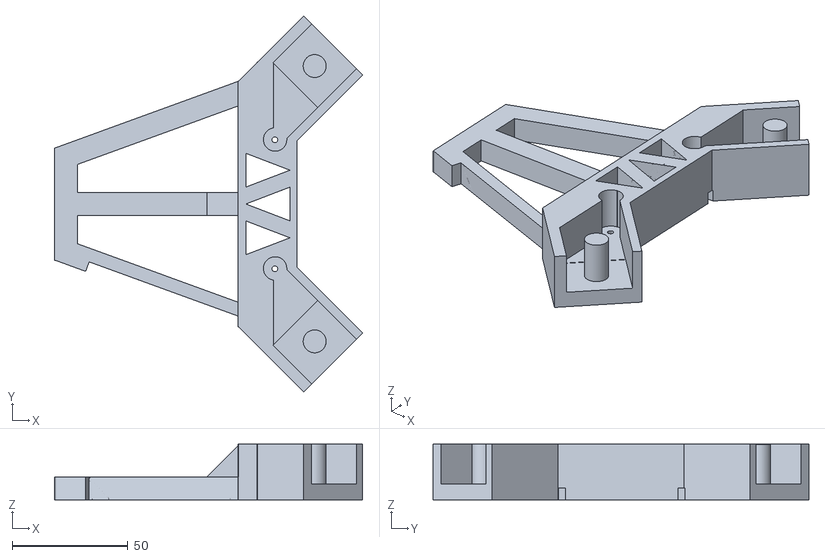
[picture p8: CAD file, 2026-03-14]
3D_Parts/Rover_Side_R_fixed.stl
133.3 x 162.5 x 24.1

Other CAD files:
3D_Parts/Rover_Side_L_fixed.stl
3D_Parts/frontal_sensor_v2.stl

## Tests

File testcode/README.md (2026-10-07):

# Les exemples de code

# 🧪 Validation de la polarité et du sens de rotation des moteurs

Ce script de test MicroPython permet de **valider de manière empirique** que vos 4 moteurs CC (2 par côté) sont câblés et connectés dans la bonne direction. Il utilise l'écran OLED local et les boutons de navigation analogiques du module uCompute pour activer chaque côté de manière indépendante.

## 📋 Prérequis matériels
* Le **uCompute Rover** entièrement assemblé mécaniquement.
* Les modules **DRV8833** insérés et les moteurs connectés.
* L'écran **OLED SSD1306** et le capteur de puissance **INA219** branchés.
* L'alimentation active (batteries) pour fournir la puissance aux moteurs.

---

## 🚀 Procédure de test et validation

1. **Préparation :** Placez le Rover sur un support (comme une cale ou une boîte de rangement) afin que **les 4 roues ne touchent pas le sol**. Cela évitera que le robot ne s'échappe ou ne chute de votre table de travail.
2. **Démarrage :** Allumez le robot et lancez le script. L'écran affiche un message d'accueil `Rover tests - Press anykey`.
3. **Lancement :** Appuyez sur n'importe quel bouton pour démarrer le programme. L'écran affiche désormais la tension de la batterie (Volts) et le courant consommé (mA) en temps réel.

### 📐 Grille de validation des commandes

Appuyez sur les boutons physiques de votre carte uCompute pour exécuter les tests suivants :

| Bouton pressé | Action logicielle | Résultat attendu sur le Rover |
| :---: | :--- | :--- |
| ⬇️ **BOUTON BAS** *(Down)* | Active le côté **DROIT** | Les deux roues du côté **Droit** doivent tourner vers l'**AVANT**. |
| ⬆️ **BOUTON HAUT** *(Up)* | Active le côté **GAUCHE** | Les deux roues du côté **Gauche** doivent tourner vers l'**AVANT**. |
| **AUCUN** *(Relâché)* | Arrêt total | Les 4 moteurs s'arrêtent instantanément. |

---

## 🛠️ Que faire en cas de mauvaise polarité ?

Comme indiqué dans la section d'assemblage électronique, les deux moteurs d'un même côté fonctionnent en paire (câblés de manière synchrone). Le module de puissance inverse naturellement la polarité du second moteur de ce même côté en raison de son orientation mécanique inversée.

* ❌ **Si une roue tourne vers l'arrière** alors que l'autre tourne vers l'avant : Débranchez le connecteur **JST-XH** du moteur défaillant, inversez ses deux fils (polarité), puis rebranchez-le.
* ❌ **Si les deux roues d'un même côté reculent** : Inversez simplement le sens de connexion global des connecteurs entre les deux moteurs de ce côté pour rétablir la bonne marche avant.

*Une fois que l'activation du bouton HAUT et du bouton BAS fait tourner toutes vos roues de manière fluide vers l'avant, votre uCompute Rover est officiellement prêt pour son premier script de déplacement autonome !*

## 💻 Logique logicielle : Le Mode RC

Le pilotage à distance repose sur un duo de scripts MicroPython hautement optimisés, répartis entre la télécommande (**Émetteur**) et le rover (**Récepteur**). Ils exploitent le protocole de communication radio 2,4 GHz via les modules **nRF24L01+**.

### 🎮 1. La Télécommande (L'Émetteur)
Le script de la télécommande échantillonne en continu les coordonnées analogiques (X, Y) du joystick via le convertisseur analogique-numérique (ADC) du RP2040.
* **Mixage vectoriel :** Le code intègre un algorithme de mixage mathématique. L'axe Y gère la marche avant/arrière et l'axe X gère le pivot. Le programme fusionne ces deux vecteurs pour calculer instantanément la puissance requise pour le moteur gauche et le moteur droit.
* **Zone neutre (*Deadzone*) :** Une zone morte de 4 % est logiciellement configurée au centre du joystick. Cela évite que les moteurs ne sillonnent ou ne grincent lorsque la télécommande est au repos.
* **Paquet compact :** Pour maximiser la portée et la réactivité, les puissances (comprises entre -100 et +100) sont compactées dans un paquet binaire ultra-léger de deux entiers signés de 16 bits (`struct.pack("hh", p_gauche, p_droite)`) avant l'envoi radio.

### 🤖 2. Le Rover (Le Récepteur)
Afin de garantir une sécurité maximale et d'éviter les pertes de contrôle, le rover sépare ses tâches logiques grâce aux deux cœurs du RP2040 :
* **Thread de communication dédié (`_thread`) :** Un second processus indépendant tourne en boucle fermée pour écouter la radio. Dès qu'un paquet arrive, il le décompresse (`struct.unpack`) et applique immédiatement la modulation de largeur d'impulsion (PWM) aux contrôleurs de moteurs DRV8833.
* **Boucle principale (Télémétrie) :** Le cœur principal gère l'affichage en temps réel sur l'écran OLED. Il interroge en permanence le capteur **INA219** pour afficher la tension de la batterie et la consommation électrique globale en milliampères (mA), faisant office de tableau de bord de diagnostic.

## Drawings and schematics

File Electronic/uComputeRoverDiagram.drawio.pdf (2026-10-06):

# uCompute Rover Diagram

## https://github.com/JPMichon/uCompute_Rover

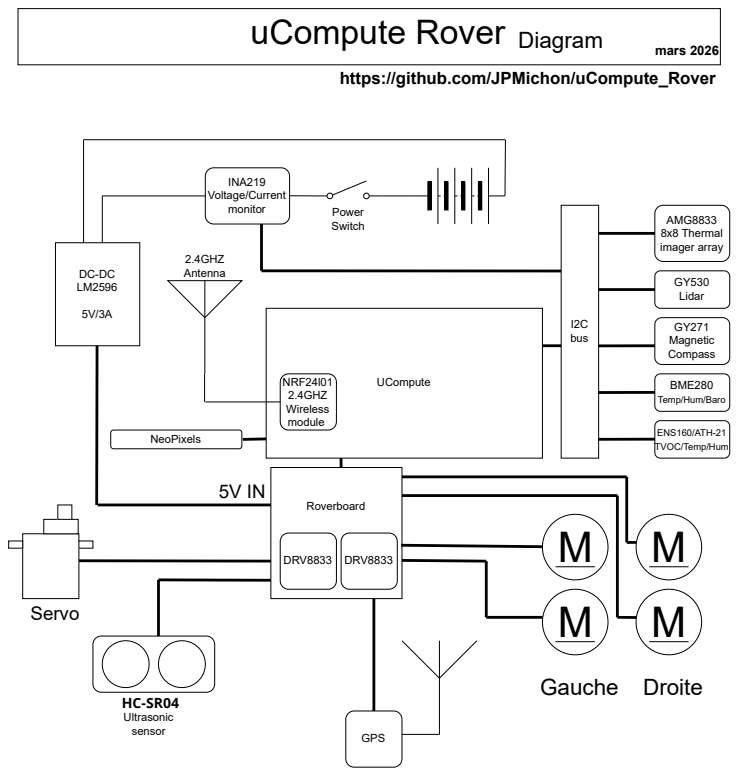
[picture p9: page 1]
Roverboard; UCompute; I2C bus; AMG8833 8x8 Thermal imager array; GY530 Lidar; GY271 Magnetic Compass; Servo; ENS160/ATH-21 TVOC/Temp/Hum; DRV8833 DRV8833; HC-SR04 Ultrasonic sensor; NRF24l01 2.4GHZ Wireless module; 2.4GHZ Antenna; NeoPixels; Gauche Droite; INA219 Voltage/Current; monitor; Power; Switch; GPS; mars 2026

BME280
Temp/Hum/Baro

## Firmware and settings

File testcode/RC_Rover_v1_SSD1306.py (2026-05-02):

#----------------------------------------------------------------
# Programme pour tester les connections des moteurs sur le Rover
#afin que ceux-ci tourne dans la bonne direction
# # il est concu pour utiliser un SSD1306 connecté sur le uCompute
#
#----------------------------------------------------------------



from machine import Pin,  I2C, SPI, PWM
from ssd1306 import SSD1306_I2C
from nrf24l01 import NRF24L01
import _thread
import struct
import ina219
import utime


#Configuration des Ports pour le uCompute V1.x
_MicroSD_Detect = 7 # détection de la présence d'une carte MicroSD (GP7)
_MicroSD_Select = 13 # définition de la pin Select du SDCARD (GP13)
_W5500_Select = 8 # définition de la pin Select du W5500 (GP8)
_W5500_Reset = 10 # définition de la pin Reset du W5500 (GP10)
_SPI1_SCK = 14 # SPI1_shared Clock
_SPI1_MOSI = 15 # SPI1_shared MOSI
_SPI1_MISO = 12 # SPI1_shared MISO
_ST7789_SCK = 2 # définition de la pin Clock du ST7789 (GP2) SPI0
_ST7789_MOSI = 3 # définition de la pin MOSI du ST7789 (GP3) SPI0
_ST7789_RESET = 4 # définition de la pin Reset du ST7789 (GP4)
_ST7789_DC = 5 # définition de la pinSelect du ST7789 (GP5)
_ST7789_BL = 6 # définition de la pinBacklit du ST7789 (GP6)
_Led_System = 25 # définition du port  del systeme (GP25)
_I2C_SDA = 20 # définition de Data du I2C(0) (GP20)
_I2C_SCL = 21 # définition de SCL du I2C(0) (GP21)
_Buzzer = 11 # définition du  buzzer (GP11)
_NeoPixel = 23 # définition du port NeoPixel (GP23)
_NeoPixel_nbr = 8 # nombre de neopixel sur le port
_EEPROM_ADDR = 0x50 # adresse du eeprom
_INA219_ADDR = 0x40 # adresse du INA219
_INA219_SHUNT_OHMS = 0.1  # Check value of shunt used with your INA219
_Boutons = 26 # définition du port analogue des boutons (GP26)


    
_Servo_pin = 28
_HCSR04_Trigger_pin = 27
_HCSR04_Echo_pin = 24
_GPS_TX = 0
_GPS_RX = 1

# uCompute NRF24l01+ Radio Module
#_SPI1_SCK = 14 # SPI1_shared Clock with SD Card
#_SPI1_MOSI = 15 # SPI1_shared MOSI with SD Card
#_SPI1_MISO = 12 # SPI1_shared MISO with SD Card
_NRF24l01_CSN = Pin(8, mode=Pin.OUT, value=1)  # Chip Select (LOW during SPI)
_NRF24l01_CE  = Pin(10, mode=Pin.OUT, value=0)  # Enable TX/RX (HIGH); standby (LOW)
_NRF24l01_IRQ  = Pin(9, mode=Pin.IN)  # IRQ (Interrupt): Optional. Goes LOW when data is received or transmission completes.
payload_size = 20
_NRF24l01_Channel=2
# RF_SETUP register
_NRF24l01_POWER_0 = const(0x00)  # -18 dBm
_NRF24l01_POWER_1 = const(0x02)  # -12 dBm
_NRF24l01_POWER_2 = const(0x04)  # -6 dBm
_NRF24l01_POWER_3 = const(0x06)  # 0 dBm
_NRF24l01_SPEED_1M = const(0x00)
_NRF24l01_SPEED_2M = const(0x08)
_NRF24l01_SPEED_250K = const(0x20)

#role = "Transmitter"
role = "Receiver"
if role == "Transmitter":
    send_pipe = b"\xe1\xf0\xf0\xf0\xf0"
    receive_pipe = b"\xd2\xf0\xf0\xf0\xf0"
else:
    send_pipe = b"\xd2\xf0\xf0\xf0\xf0"
    receive_pipe = b"\xe1\xf0\xf0\xf0\xf0"
    
#-----------------------------------------------------------------------------------
#Initialisation
i2c=I2C(0,sda=Pin(_I2C_SDA), scl=Pin(_I2C_SCL), freq=200000)
#Initialisation des IOs

System_LED = Pin(_Led_System,Pin.OUT)
MicroSD_Detect = Pin(_MicroSD_Detect,Pin.IN)
BTN_Analogue = machine.ADC(_Boutons) #Diviseur de tension des boutons

#Configuration des Ports pour le Roverboard
_nsleep_Motors = 22 # desactivation des moteurs de traction (0=disable, 1=enable)
_MoteurDroiteA = PWM(Pin(18))
_MoteurDroiteB = PWM(Pin(19))
_MoteurGaucheA = PWM(Pin(16))
_MoteurGaucheB = PWM(Pin(17))

# Fréquence PWM (entre 1000 et 40000 Hz recommandé pour DRV8833)
for p in [_MoteurGaucheA, _MoteurGaucheB, _MoteurDroiteA, _MoteurDroiteB]:
    p.freq(30000)

nsleep=Pin(_nsleep_Motors, Pin.OUT)
nsleep.value(1) #Pour enabler les modules DRB8833, la pin nsleep doit etre a 1
# -----------------------------------
#Configuration de la résolution du OLED
oled = SSD1306_I2C(128, 64, i2c)  
sensor_INA219 = ina219.INA219(i2c, addr=_INA219_ADDR)

def PrintTTY(texte):
#------------------------------------------------------------------------------------
# Fonctions permettant d'utiliser le display comme un TTY pour afficher les logs
# et de scroller automatiquement
#------------------------------------------------------------------------------------
    global TTY_Pointer # en utilisant une variable global, cela permet d'initialiser une seule fois la variable. Il y a surement une facon plus elegante, pour garder l'etat d'une variable locale dans une fonction. 
    
    if TTY_Pointer < WrapScreen:
        TTY[TTY_Pointer]=texte[:15] # je limite le texte a la largeur de l'ecran
        TTY_Pointer+=1
    else: #  dans le cas ou je suis a la derniere ligne de l'ecran, je decale vers le haut
        for i in range(WrapScreen-1):
            TTY[i] = TTY[i+1] # je decale vers le haut
        TTY[TTY_Pointer-1]=texte[:15] # je limite le texte a la largeur de l'ecran
# j'affiche le texte sur l'ecran 
    fbuf.fill(st7789.BLACK)
    for i in range(TTY_Pointer):
        line_ptr=i*20
        fbuf.large_text(TTY[i],0,line_ptr,2,st7789.LIME)
     
    display.blit_buffer(buffer, 0, 0, buffer_width, buffer_height) # render display

def setup_NRF24l01():
    print("Initialising the nRF24L0+ Module")
    spi = SPI(1, sck=Pin(_SPI1_SCK), mosi=Pin(_SPI1_MOSI), miso=Pin(_SPI1_MISO))
    nrf = NRF24L01(spi, _NRF24l01_CSN, _NRF24l01_CE, channel=_NRF24l01_Channel,  payload_size=payload_size)
    nrf.set_power_speed(_NRF24l01_POWER_3, _NRF24l01_SPEED_250K)  # Best for point to point links
    nrf.open_tx_pipe(send_pipe)
    nrf.open_rx_pipe(1, receive_pipe)
    nrf.start_listening()
    
    return nrf

def WaitInputKey():
    while BTN_Analogue.read_u16()>64000: # attend any key
        utime.sleep(.05)
        
def SplashScreen():    
    oled.fill(0)
    oled.text('----------------', 0, 0)
    oled.text('Rover tests', 25, 10)
    oled.text('----------------', 0, 20)
    oled.text('Rover RC', 25, 35)
    oled.text('Press anykey', 20, 55)
    oled.show()

def Read_Keys():
    _read = BTN_Analogue.read_u16()
    _KeyPress='null'
    if _read < 8000: #Down
        _KeyPress='down'
    elif _read < 13000: #Select
        _KeyPress='select'
    elif _read < 18000: # Up
        _KeyPress='up'          
    #print(str(_read)) #pour le debuggage affiche la lecture de la clé dans la console    
    return _KeyPress #+str(_read)

def Network_thread():
    nrf.start_listening()
    global p_gauche
    global p_droit
    global data_update
    p_gauche = 0
    p_droit = 0
    
    while True:
        if nrf.any():
            buf = nrf.recv()
            # Décompression des deux entiers 'short' signés
            temp_gauche = p_gauche
            temp_droit = p_droit
            p_gauche, p_droit = struct.unpack("hh", buf)
            controler_moteur(_MoteurGaucheA, _MoteurGaucheB, p_gauche)
            controler_moteur(_MoteurDroiteA, _MoteurDroiteB, p_droit)
        System_LED.toggle() # je fais flasher la led GP25 afin de valider que la tache fonctionne

        
def controler_moteur(in1, in2, puissance):
    # Conversion -100/100 vers 0-65535 (duty cycle MicroPython)
    duty = int((abs(puissance)/4+75) * 655.35)
    if puissance > 0:   # Marche avant
        in1.duty_u16(duty)
        in2.duty_u16(0)
    elif puissance < 0: # Marche arrière
        in1.duty_u16(0)
        in2.duty_u16(duty)
    else:               # Stop
        in1.duty_u16(0)
        in2.duty_u16(0)
  


#---------------------------------------------------------------------------------
# Main loop
#---------------------------------------------------------------------------------
SplashScreen()
WaitInputKey()
# tentative d'initialisation du module du NRF24l01
try:
    nrf = setup_NRF24l01()
except OSError:
    print("NRF24l01 not found")
    oled.fill(0)
    oled.text('err Comm. Module', 0, 0)
    oled.text('-----------------', 0, 10)
    oled.text("nRF24L0+", 25, 30)
    oled.text("not found", 20, 40)
    oled.show()
    while True: # puisqu'il y a une erreure, je boucle en infini car cela ne sert a rien de continuer
        utime.sleep(0.2)
# demmarage de la seconde tache s'occupant de la gestion des communication et du controle des moteurs
_thread.start_new_thread(Network_thread, ()) # network/ motors controls

while True:
    oled.fill(0)
    oled.text("Curr.:" +str(f"{sensor_INA219.current:.2f}"+" mA"),20, 0)
    oled.text("Volts:" +str(f"{sensor_INA219.bus_voltage:.2f}"+" V"),20, 10)
    #oled.text("Power:" +str(f"{((sensor_INA219.current/100)*sensor_INA219.bus_voltage):.3f}"+" Watt"))
    oled.text('Left      Right', 0, 40)
    oled.text(str(p_gauche)+"        "+str(p_droit), 0, 50)
    # Application aux moteurs
    print(f"Moteurs -> G: {p_gauche}, D: {p_droit}")
    oled.show()

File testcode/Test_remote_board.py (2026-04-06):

from machine import SPI, Pin
from time import sleep
import st7789 as st7789
import utime
import framebuf2
import os

#Configuration des Ports pour le uCompute V1.x
_MicroSD_Detect = 7 # détection de la présence d'une carte MicroSD (GP7)
_MicroSD_Select = 13 # définition de la pin Select du SDCARD (GP13)
_SPI1_SCK = 14 # SPI1_shared Clock
_SPI1_MOSI = 15 # SPI1_shared MOSI
_SPI1_MISO = 12 # SPI1_shared MISO
_ST7789_SCK = 2 # définition de la pin Clock du ST7789 (GP2) SPI0
_ST7789_MOSI = 3 # définition de la pin MOSI du ST7789 (GP3) SPI0
_ST7789_RESET = 4 # définition de la pin Reset du ST7789 (GP4)
_ST7789_DC = 5 # définition de la pinSelect du ST7789 (GP5)
_ST7789_BL = 6 # définition de la pinBacklit du ST7789 (GP6)
_Led_System = 25 # définition du port  del systeme (GP25)
_I2C_SDA = 20 # définition de Data du I2C(0) (GP20)
_I2C_SCL = 21 # définition de SCL du I2C(0) (GP21)
_Buzzer = 11 # définition du  buzzer (GP11)
_NeoPixel = 23 # définition du port NeoPixel (GP23)
_NeoPixel_nbr = 1 # nombre de neopixel sur le port
_Boutons = 26 # définition du port analogue des boutons (GP26)
# Configuration du port serie sur le connecteur
_UART = 0 # UART par defaut
_TX_PIN = 0 # TX Pin (GP0)
_RX_PIN = 1 # TX Pin (GP1)
_BaudRate = 9600 # Baud rate du UART

# Configuration Remote Module
_analog_X = machine.ADC(27)
_analog_Y = machine.ADC(28)
_Led_Obstacle = 17
_Led_Warning = 16 
_Led_Lost_comm = 24 
_SW_A = 19
_SW_B = 18
_SW_C = 22
#
#
# set landscape screen
screen_width = 240
screen_height = 240
screen_rotation = 1
#gestion de la sortie STDOUT sur l'ecran LCD
TTY_Pointer=0
WrapScreen= int(screen_height/20)-1  # nombre de ligne avant de wrapper sur l'écran /10 si charactere 8x8
TTY = ['']*WrapScreen# creation d'une matrice pour emuler un TTY

#-------------------------------------
#
# Début de l'initialisation 
#
spi = SPI(0,baudrate=20000000,polarity=1,phase=1,bits=8,firstbit=SPI.MSB,sck=Pin(_ST7789_SCK),mosi=Pin(_ST7789_MOSI))
display = st7789.ST7789(spi,screen_width,screen_height,reset=Pin(_ST7789_RESET, Pin.OUT),dc=Pin(_ST7789_DC, Pin.OUT),backlight=Pin(_ST7789_BL, Pin.OUT),rotation=screen_rotation)

#Initialisation des IOs
LED_WARNING = Pin(_Led_Warning, Pin.OUT)
System_LED = Pin(_Led_System, Pin.OUT)
LED_COMM_LOST = Pin(_Led_Lost_comm, Pin.OUT)
LED_OBSTACLE = Pin(_Led_Obstacle, Pin.OUT)

BTN_Analogue = machine.ADC(_Boutons) #Diviseur de tension des boutons
SWITCH_A=Pin(_SW_A,Pin.IN)
SWITCH_B=Pin(_SW_B,Pin.IN)
SWITCH_C=Pin(_SW_C,Pin.IN)

# Initialisation du FrameBuffer
# FrameBuffer needs 2 bytes for every RGB565 pixel
buffer_width = 240
buffer_height = 240
buffer = bytearray(buffer_width * buffer_height * 2)
fbuf = framebuf2.FrameBuffer(buffer, buffer_width, buffer_height, framebuf2.RGB565)
fbuf.fill(st7789.WHITE)

def WaitInputKey():
    while BTN_Analogue.read_u16()>64000: # attend any key
        utime.sleep(.05)

def PrintTTY(texte):
#------------------------------------------------------------------------------------
# Fonctions permettant d'utiliser le display comme un TTY pour afficher les logs
# et de scroller automatiquement
#------------------------------------------------------------------------------------
    global TTY_Pointer # en utilisant une variable global, cela permet d'initialiser une seule fois la variable. Il y a surement une facon plus elegante, pour garder l'etat d'une variable locale dans une fonction. 
    
    if TTY_Pointer < WrapScreen:
        TTY[TTY_Pointer]=texte[:15] # je limite le texte a la largeur de l'ecran
        TTY_Pointer+=1
    else: #  dans le cas ou je suis a la derniere ligne de l'ecran, je decale vers le haut
        for i in range(WrapScreen-1):
            TTY[i] = TTY[i+1] # je decale vers le haut
        TTY[TTY_Pointer-1]=texte[:15] # je limite le texte a la largeur de l'ecran
# j'affiche le texte sur l'ecran 
    fbuf.fill(st7789.BLACK)
    for i in range(TTY_Pointer):
        line_ptr=i*20
        fbuf.large_text(TTY[i],0,line_ptr,2,st7789.LIME)
     
    display.blit_buffer(buffer, 0, 0, buffer_width, buffer_height) # render display



def SplashScreen():
    fbuf.fill(st7789.WHITE) # Efface l'écran (le framefuffer)
    # le vrai splash screen
    fbuf.large_text('Remote', 10, 20, 3, st7789.RED)
    fbuf.large_text('Test', 30, 44, 3, st7789.RED)
    
    fbuf.large_text("SYSTEM:", 1, 130, 1, st7789.BLUE)
    fbuf.large_text(str(os.uname().machine), 1, 140, 1, st7789.BLACK)
    fbuf.large_text("Freq:"+ str(machine.freq()/1e6) +" Mhz", 1, 150, 1, st7789.BLACK)
    fbuf.large_text('[Press AnyKey]', 5, 220, 2, st7789.BLUE)  # double size text
    display.blit_buffer(buffer, 0, 0, buffer_width, buffer_height) # render display
    
def MainDisplay(p_gauche, p_droite):    
    fbuf.fill(st7789.WHITE) # Efface l'écran (le framefuffer)
    fbuf.large_text('Main Display', 10, 0, 2, st7789.RED)
    fbuf.large_text('Motors', 10, 200, 2, st7789.BLACK)
    fbuf.large_text(str(p_gauche) +"  " + str(p_droite), 10, 220, 2, st7789.BLACK)
    display.blit_buffer(buffer, 0, 0, buffer_width, buffer_height) # render display



def flash_led(times:int=None):
    ''' Flashed the built in LED the number of times defined in the times parameter '''
    for _ in range(times):
        System_LED(1)
        sleep(0.01)
        System_LED(0)
        sleep(0.01)
        
#--------------------------------------------------------------------------------------------------------------------------------------------------
#  Main loop
#
#--------------------------------------------------------------------------------------------------------------------------------------------------

SplashScreen()
WaitInputKey()
resolution=65535
LED_OBSTACLE.high()
LED_WARNING.high()
LED_COMM_LOST.high()

center = resolution / 2

while True:
    # Read 16-bit value (0 - 65535)
    fbuf.fill(st7789.WHITE) # Efface l'écran (le framefuffer)
    value_X = _analog_X.read_u16()
    value_Y = _analog_Y.read_u16()
    x = ((value_X - center) / center) * 100
    y = ((value_Y - center) / center) * 100
    # --- Exemple d'utilisation ---
    # Si x=65535 (droite toute) et y=65535 (avant toute)
    fbuf.circle(int(120-x), int(120+y), 4, st7789.BLACK,True)
    if not(SWITCH_A.value()):
        LED_OBSTACLE.toggle()
        sleep(0.1)
        
    if not(SWITCH_B.value()):
        LED_WARNING.toggle()
        sleep(0.1)
        
    if not(SWITCH_C.value()):
        LED_COMM_LOST.toggle()
        sleep(0.1)
               
    display.blit_buffer(buffer, 0, 0, buffer_width, buffer_height) # render display
    

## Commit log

2026-03-14 Fichiers STL pour l'impression du Rover
    [Electronic_plate_v2_uCRP2040.stl, Rover_Legs_V2.stl, Rover_Side_L_fixed.stl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]
2026-03-14 Update README with materials and components list
    Added required materials and optional components for the uCompute Rover.
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2026-03-14 Fix formatting in README for optional materials
    Corrected formatting and added spacing in the optional materials section.
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2026-03-14 Update README with Rover module information
    Added details about the Rover module and its power requirements.
2026-03-14 Update README with image and material list
    Add image link and update material requirements.
2026-03-16 Fix image link for Remote PCB in README
    Updated image link for the 3D PCB module in README.
2026-04-01 Update readme with printing details and links
    Added additional information and links for 3D parts.
2026-04-01 Update readme with printing details and links
    Added links for Rover parts and printing instructions.
2026-04-01 Update leg printing instructions in readme
    Added warning about two versions of the leg file and clarified printing instructions.
2026-04-01 Update readme with warning about leg file versions
    Added a note about the two versions of the leg file and their specifications.
2026-04-01 Enhance readme with 3D parts details and links
    Added detailed descriptions and links for various 3D printed parts including sides, legs, electronic plate, tablet, collision detection, and top tablet.
2026-04-01 Revise Rover Legs version information in readme
    Updated the readme to reflect changes in Rover Legs version and added a note about the new version.
2026-04-01 Update readme with version details and electronic board info
    Added a note about the two versions of the Rover Legs and updated the electronic board information.
2026-04-06 Add files via upload
    Nouvelle version supportant les modules MK1, Mini et GT24
2026-04-12 Add files via upload
    update version
    [RC_remote_v1.stl]
2026-04-12 Add files via upload
    ajustement de la hauteur des supports
    [RC_remote_v1.stl]
2026-10-05 Update readme with assembly instructions
    Added note about assembly and glue for parts.
2026-10-05 Update readme with clearer assembly instructions
    Clarified the description of the Rover parts assembly.
2026-10-05 Update readme with image and assembly details
    Added an image reference and clarified assembly instructions.
2026-10-05 Enhance readme with parts and assembly instructions
    Updated the readme with a detailed parts table and assembly guide for the Rover.
2026-10-05 Update readme with motor and wheel installation steps
    Added instructions for motor and wheel attachment.
2026-10-05 Update motor wiring instructions in readme
    Added information about using JST-XH connectors for motor wiring.
2026-10-05 Revise assembly steps for structural security recommendations
    Updated assembly instructions to include optional use of cyanoacrylate glue for structural security in steps 6 and 7.
2026-10-05 Fix spelling and grammar in readme.md
    Correct spelling and grammar in the French text regarding assembly instructions.
2026-10-05 Fix grammar in assembly note in readme
    Corrected capitalization and punctuation in the note about assembly.
2026-10-05 Enhance readme with detailed assembly instructions
    Added detailed instructions for securing the electronic plate and Ucompute module, including specific screw sizes and methods for assembly.
2026-10-05 Fix typo in readme.md regarding screw placement
2026-10-05 Update readme with plastic type recommendation
    Added a note about plastic type and encouraged creativity in material use.
2026-10-05 Revise README for architecture and module details
    Updated the README to include new sections on electronic architecture, parent repository, and system core. Added details about extension modules and wireless communication.
2026-10-05 Revise readme for component names and assembly images
    Updated the readme to reflect changes in component names and added images for the assembled uCompute Rover.
2026-10-05 Update README with schematic image placeholder
    Added an image placeholder for the electronic schematic.
2026-10-05 Update README with motor installation details
    Added installation instructions for motors with images.
2026-10-05 Fix typos in motor installation section of README
    Corrected spelling and formatting errors in the installation instructions for motors.
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2026-10-05 Remove motor installation step and update assembly note
    Removed step 7 regarding motor and wheel installation, and added a note about the continuation of assembly in the electronics section.
2026-10-05 Update README with motor installation details
    Added installation requirements and instructions for motors.
2026-10-05 Revise motor installation section in README
    Updated installation instructions for motors with clearer formatting and added images.
2026-10-06 Update README with motor pairing and Mecanum details
    Clarified motor pairing functionality and added note about future Mecanum wheel module.
2026-10-06 Update README with additional schematic image
    Added a new image to the README for better visualization.
2026-10-06 Update README to emphasize hardware adaptability
    Clarified the adaptability of the motor control module for various development platforms.
2026-10-06 Enhance README with clearer module adaptability details
    Emphasized the flexibility of the motor control module for various platforms.
2026-10-06 Update README to emphasize project flexibility
    Clarified the open architecture and compatibility of the motor control module with various development platforms.
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2026-10-06 Update README with motor connection and operation details
    Added a note about ensuring consistent polarity when soldering motor connections and clarified the operation of left and right motors in pairs.
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2026-10-06 Revise installation steps and add power fixation section
    Updated installation instructions and added a section for power fixation using Velcro.
2026-10-06 Revise power fixation section in README
    Updated the section on power fixation to improve clarity and consistency in terminology. Changed 'velcro' to 'Velcro' for proper branding.
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2026-10-07 Update README with hot glue usage note
    Added a note about the melting point of hot glue and its impact on 3D printed parts.
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2026-10-07 Revise hot glue note for clarity and formatting
    Updated note on hot glue melting point and usage caution.
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2026-10-07 Fix formatting in assembly guide section
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2026-10-07 Correct spelling of 'Motoréducteurs' to 'Moteurs réductés'
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2026-10-26 Fix typo in Fan Control GPIO description
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
